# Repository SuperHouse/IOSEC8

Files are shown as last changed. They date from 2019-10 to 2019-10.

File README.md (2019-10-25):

Security Sensor Breakout
========================
Copyright 2017-2019 SuperHouse Automation Pty Ltd: www.superhouse.tv  

Based on the circuit described in the "Security / Automation Sensors"
project in the book "Practical Arduino", this breakout allows up to 8
security sensors to be connected with full End-Of-Line (EOL) support to
detect tampering.

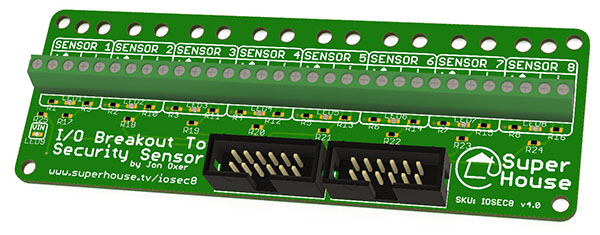
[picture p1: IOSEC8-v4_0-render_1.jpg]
PCB render


Supported sensors include:

 * PIR (passive infrared) motion detectors.
 * Microwave motion detectors.
 * Reed switches.
 * Glass break detectors.
 * Gas detectors.

End-Of-Line technology allows the system to detect a variety of events
using a single cable pair to the sensor, including:

 * Sensor triggered.
 * Sensor cable cut.
 * Sensor cable short-circuited.
 * Sensor housing opened (even when system is disarmed)

Compatible with I/O breakouts such as the I/O Breakout and I/O Breakout
Mega, both from SuperHouse.

Features:

 * Supports 8 sensor channels simultaneously.
 * Sensor power supply connections.
 * "Sensor power on" LED.
 * Optional status LEDs for each channel

More information is available at:

  http://www.superhouse.tv/iosec8  

INSTALLATION
------------
The design is saved as an EAGLE project. EAGLE PCB design software is
available from www.cadsoftusa.com free for non-commercial use. To use
this project download it and place the directory containing these files
into the "eagle" directory on your computer. Then open EAGLE and
navigate to the project.

DISTRIBUTION
------------
The specific terms of distribution of this project are governed by the
license referenced below.

LICENSE
-------
Licensed under the TAPR Open Hardware License (www.tapr.org/OHL).
The "license" folder within this repository also contains a copy of
this license in plain text format.

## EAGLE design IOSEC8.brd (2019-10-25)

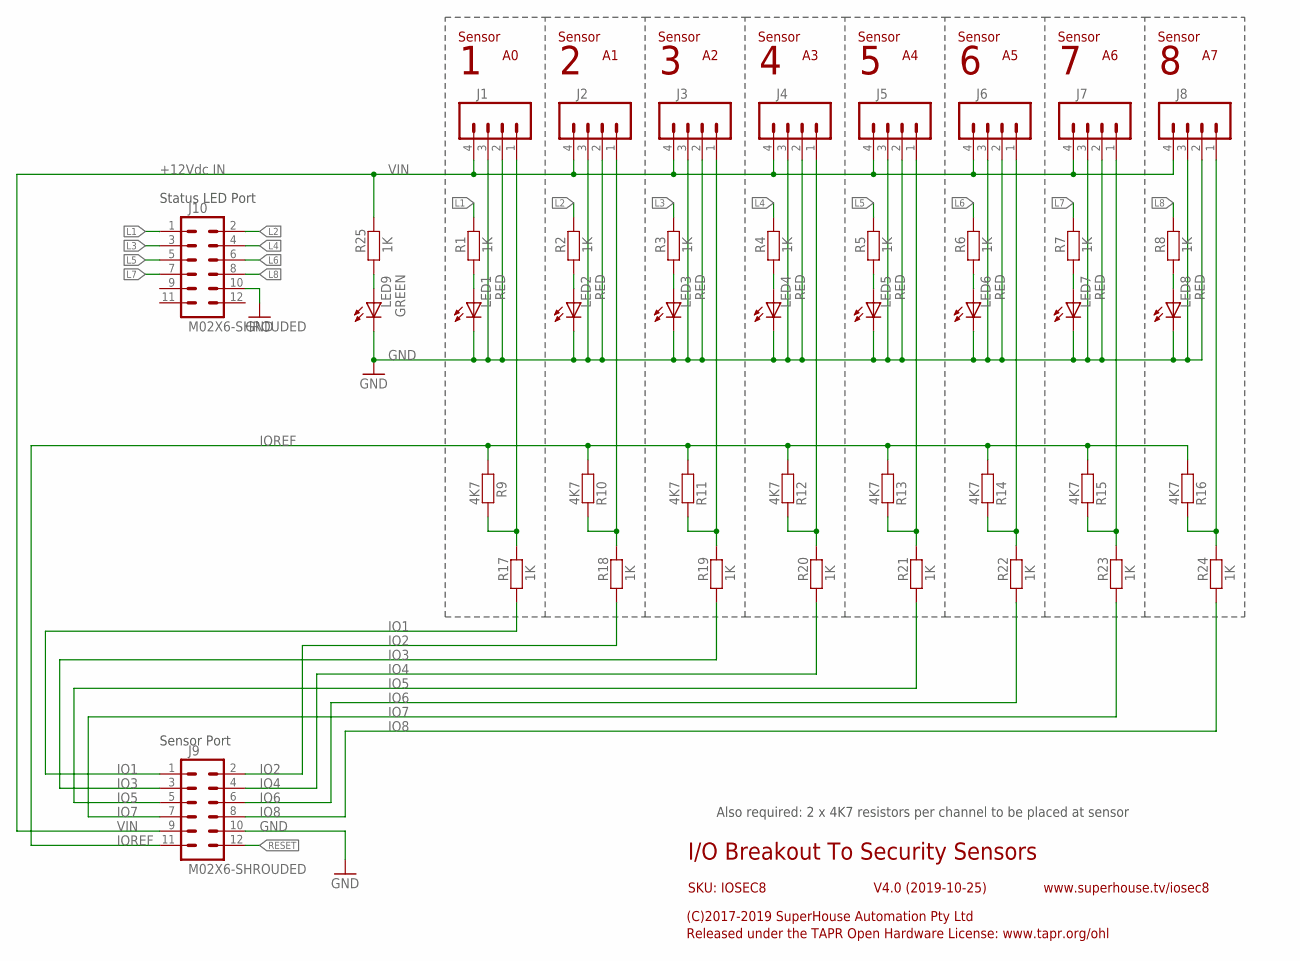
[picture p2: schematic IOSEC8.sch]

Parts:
J1, J2, J3, J4, J5, J6, J7, J8: M04-SCREW-3.5MM; SCREWTERMINAL-3.5MM-4
J9, J10: M02X6-SHROUDED; 2X06-SHROUDED
LED1, LED2, LED3, LED4, LED5, LED6, LED7, LED8: RED; LED-0603
LED9: GREEN; LED-0603
R1, R2, R3, R4, R5, R6, R7, R8, R17, R18, R19, R20, R21, R22, R23, R24, R25: 1K; R0603
R9, R10, R11, R12, R13, R14, R15, R16: 4K7; R0603

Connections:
GND: J1.2, J1.3, J2.2, J2.3, J3.2, J3.3, J4.2, J4.3, J5.2, J5.3, J6.2, J6.3, J7.2, J7.3, J8.2, J8.3, J9.10, J10.10, LED1.C, LED2.C, LED3.C, LED4.C, LED5.C, LED6.C, LED7.C, LED8.C, LED9.C
IO1: J9.1, R17.1
IO2: J9.2, R18.1
IO3: J9.3, R19.1
IO4: J9.4, R20.1
IO5: J9.5, R21.1
IO6: J9.6, R22.1
IO7: J9.7, R23.1
IO8: J9.8, R24.1
IOREF: J9.11, R9.1, R10.1, R11.1, R12.1, R13.1, R14.1, R15.1, R16.1
L1: J10.1, R1.2
L2: J10.2, R2.2
L3: J10.3, R3.2
L4: J10.4, R4.2
L5: J10.5, R5.2
L6: J10.6, R6.2
L7: J10.7, R7.2
L8: J10.8, R8.2
unnamed: LED9.A, R25.1
unnamed: LED1.A, R1.1
unnamed: J2.1, R10.2, R18.2
unnamed: J5.1, R13.2, R21.2
unnamed: J6.1, R14.2, R22.2
unnamed: J7.1, R15.2, R23.2
unnamed: J8.1, R16.2, R24.2
unnamed: LED2.A, R2.1
unnamed: LED3.A, R3.1
unnamed: LED4.A, R4.1
unnamed: LED5.A, R5.1
unnamed: LED6.A, R6.1
unnamed: LED7.A, R7.1
unnamed: LED8.A, R8.1
unnamed: J3.1, R11.2, R19.2
unnamed: J4.1, R12.2, R20.2
unnamed: J1.1, R9.2, R17.2
RESET: J9.12
VIN: J1.4, J2.4, J3.4, J4.4, J5.4, J6.4, J7.4, J8.4, J9.9, R25.2

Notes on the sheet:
Sensor
+12Vdc IN
I/O Breakout To Security Sensors
V4.0 (2019-10-25)
SKU: IOSEC8
(C)2017-2019 SuperHouse Automation Pty Ltd
Released under the TAPR Open Hardware License: www.tapr.org/ohl
www.superhouse.tv/iosec8
Also required: 2 x 4K7 resistors per channel to be placed at sensor
Sensor Port
Status LED Port

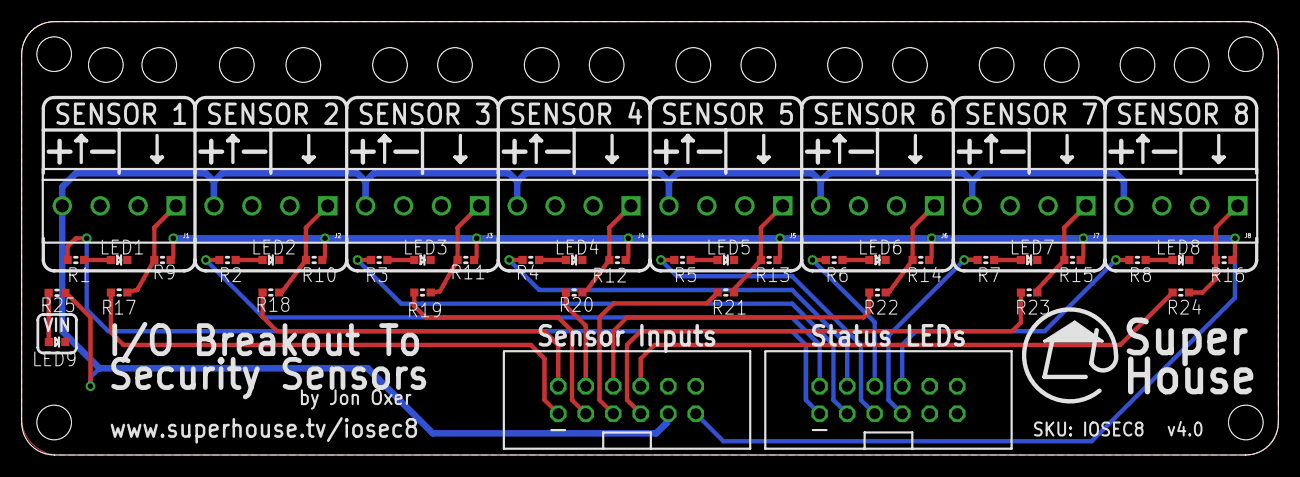
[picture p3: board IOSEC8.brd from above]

Board: 2 copper layers, 116.0 x 40.0 mm, 44 parts (0 on the bottom side), 36 nets.

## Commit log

2017-07-25 Initial project import
    [IOSEC8.brd, IOSEC8.sch]
2017-07-25 Moved to metric grid for v2.0 release
    [IOSEC8.brd, IOSEC8.sch]
2017-08-03 Improved position of part designators
    [IOSEC8.brd]
2018-01-24 Added second IO port for status LEDs. Ready for v3.0 release
    [IOSEC8.brd, IOSEC8.sch]
2018-04-11 Improved value labels for assembly guide
    [IOSEC8.brd]
2019-10-25 Massive update to reduce PCB size for v4.0 release
    [IOSEC8.brd, IOSEC8.sch]
